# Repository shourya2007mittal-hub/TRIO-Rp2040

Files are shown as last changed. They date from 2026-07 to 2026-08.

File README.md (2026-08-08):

# TRIO-Rp2040


So I made on a Dev-board based on Rp-2040 with similar size constrain like Xiao-Rp2040 but with more available pins then Xiao. So I used the smallest size of resistors and capacitors . It has access to a total of 21 GPI0 and 4 Analog . 6 Pins act as dual purpose. It holds an USB-C Type interference for communication and 3.3V Voltage regulator and Crystal oscillator , Flash Memory , boot Switch  and more . 

## Why This

I made this as an alternative for  Xiao-Rp2040. Every time we need a small rp2040 microcontroller we surely need to go with Xiao boards . I made this so that I could use it for my upcoming projects related to Micro pad  and other IOT related things.

## Features

- Based on RP-2040 Chip
- Has MCP1700x-330xxTT as Voltage Regulator 
- Has W25Q16JVUXIQTR as Flash Memory
- Has 3 set of 7 connector pins  
- Has 2 set of 2 connector pins for GND and 3.3V
- It is compatible to a breadboard 

## Cost Summary (BOM)

| Item | Quantity | Price (USD) | Source |
|---|---|---|---|
| PCB + PCBA + Shipping  | 1 | $81.91 | JLCPCB |

**Total Estimated Cost:** **$81.91**

### Schematic


### PCB Design



### 3D Design



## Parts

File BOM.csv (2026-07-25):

Item | Quantity | Price | Source
PCB + PCBA + Shipping | 1 | 81.91 | JLCPCB

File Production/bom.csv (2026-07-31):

Designator | Footprint | Quantity | Value | LCSC Part #
C1 | 0201 | 1 | 1uF
C13, C14 | 0201 | 2 | 10uF
C15, C16 | 0201 | 2 | 33pF
C17, C2, C3, C4 | 0201 | 4 | 0.1uF
J1 | USB_C_Receptacle_G-Switch_GT-USB-7010ASV | 1 | USB_C_Receptacle_USB2.0_16P
J2, J3 | Molex_SL_171971-0008_1x08_P2.54mm_Vertical | 2 | Conn_01x08_Pin
R1, R2 | 0201 | 2 | 33 R
R3, R4 | 0201 | 2 | 50K
R5, R6 | 0201 | 2 | 1K
R7 | 0201 | 1 | 10K
SW1 | SW_Push_SPST_NO_Alps_SKRK | 1 | SW_Push
U1 | QFN-56-1EP_7x7mm_P0.4mm_EP3.2x3.2mm | 1 | RP2040
U2 | SOT-23 | 1 | MCP1700x-330xxTT
U4 | Winbond_USON-8-1EP_3x2mm_P0.5mm_EP0.2x1.6mm | 1 | W25Q16JVUXIQ TR
Y1 | Crystal_SMD_1210-4Pin_1.2x1.0mm | 1 | 12 MHz

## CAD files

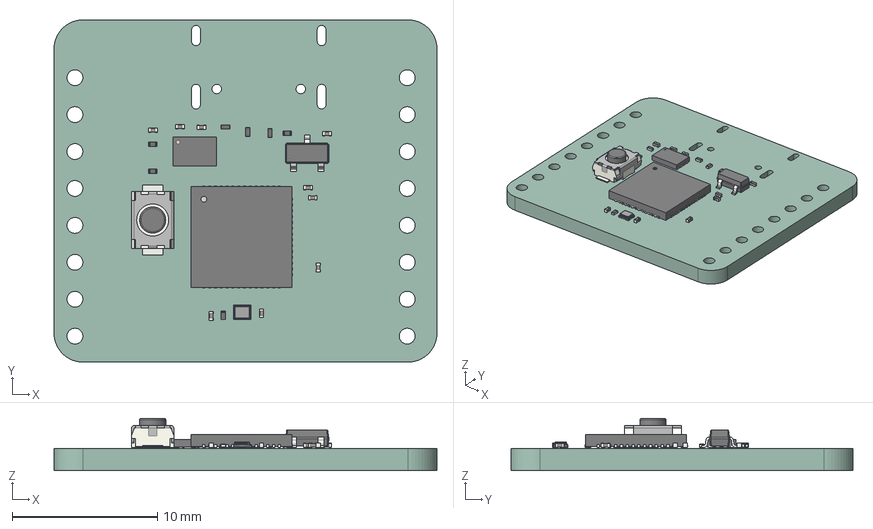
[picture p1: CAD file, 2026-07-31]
CAD/TRIO Rp2040.step
26.4 x 23.6 x 3.59 mm
R_0201_0603Metric x 7
C_0201_0603Metric x 9
Crystal_SMD_1210-4Pin_1.2x1.0mm
Winbond_USON-8-1EP_3x2mm_P0.5mm_EP0.2x1.6mm
SOT-23
QFN-56-1EP_7x7mm_P0.4mm_EP3.2x3.2mm
SW_Push_SPST_NO_Alps_SKRK
TRIO Rp2040_PCB

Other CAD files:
CAD/TRIO Rp2040.f3d

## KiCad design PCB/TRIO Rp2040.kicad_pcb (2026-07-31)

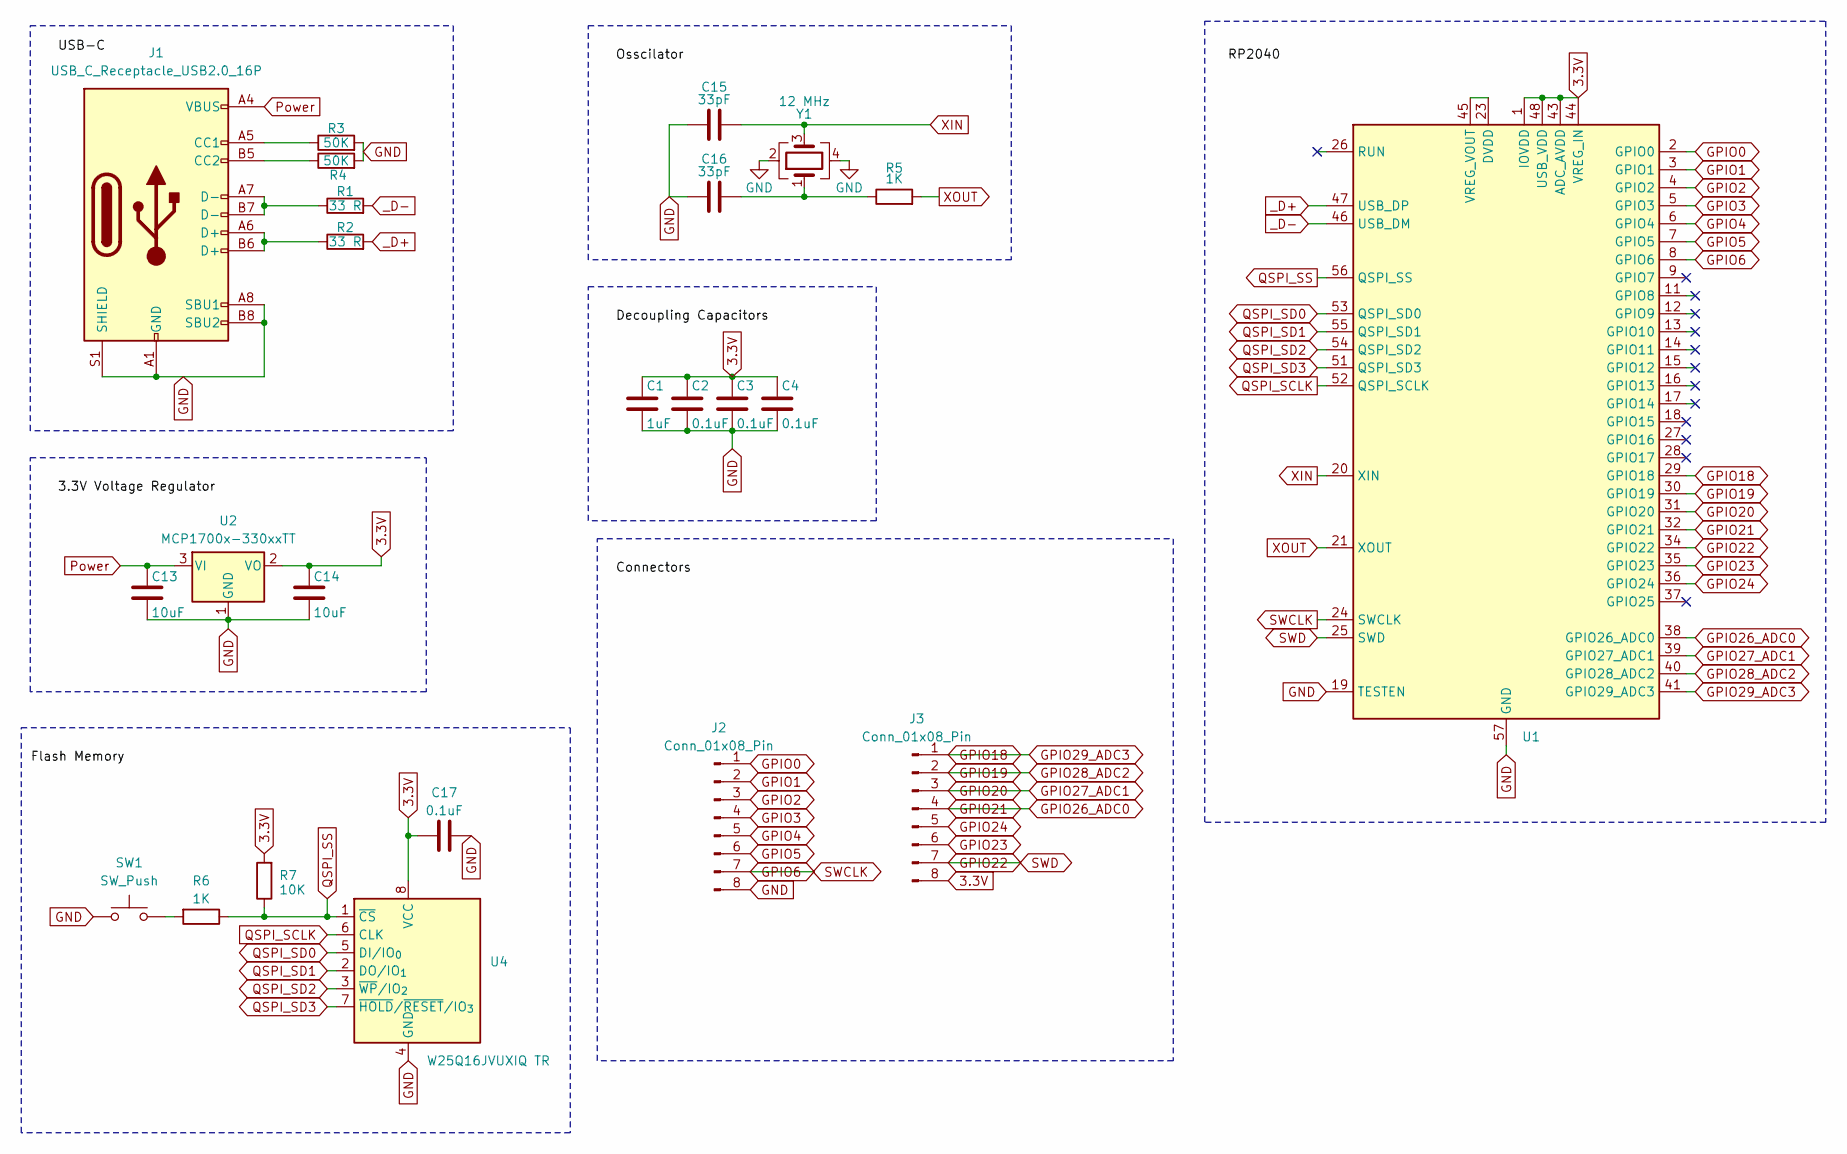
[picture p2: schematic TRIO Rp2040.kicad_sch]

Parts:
C1: 1uF; C_0201_0603Metric
C2, C3, C4, C17: 0.1uF; C_0201_0603Metric
C13, C14: 10uF; C_0201_0603Metric
C15, C16: 33pF; C_0201_0603Metric
J1: USB_C_Receptacle_USB2.0_16P; USB_C_Receptacle_G-Switch_GT-USB-7010ASV
J2, J3: Conn_01x08_Pin; Molex_SL_171971-0008_1x08_P2.54mm_Vertical
R1, R2: 33 R; R_0201_0603Metric
R3, R4: 50K; R_0201_0603Metric
R5, R6: 1K; R_0201_0603Metric
R7: 10K; R_0201_0603Metric
SW1: SW_Push; SW_Push_SPST_NO_Alps_SKRK
U1: RP2040; QFN-56-1EP_7x7mm_P0.4mm_EP3.2x3.2mm
U2: MCP1700x-330xxTT; SOT-23
U4: W25Q16JVUXIQ TR; Winbond_USON-8-1EP_3x2mm_P0.5mm_EP0.2x1.6mm
Y1: 12 MHz; Crystal_SMD_1210-4Pin_1.2x1.0mm

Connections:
3.3V: C1.1, C2.1, C3.1, C4.1, C14.1, C17.1, J3.8, R7.2, U1.1 (IOVDD), U1.10 (IOVDD), U1.22 (IOVDD), U1.33 (IOVDD), U1.42 (IOVDD), U1.43 (ADC_AVDD), U1.44 (VREG_IN), U1.48 (USB_VDD), U1.49 (IOVDD), U2.2 (VO), U4.8 (VCC)
GND: C1.2, C2.2, C3.2, C4.2, C13.2, C14.2, C15.1, C16.1, C17.2, J1.A1 (GND), J1.A8 (SBU1), J1.A12 (GND), J1.B1 (GND), J1.B8 (SBU2), J1.B12 (GND), J1.S1 (SHIELD), J2.8, R3.2, R4.2, SW1.1, U1.19 (TESTEN), U1.57 (GND), U2.1 (GND), U4.4 (GND), Y1.2, Y1.4
GPIO0: J2.1, U1.2 (GPIO0)
GPIO1: J2.2, U1.3 (GPIO1)
GPIO2: J2.3, U1.4 (GPIO2)
GPIO3: J2.4, U1.5 (GPIO3)
GPIO4: J2.5, U1.6 (GPIO4)
GPIO5: J2.6, U1.7 (GPIO5)
GPIO6: J2.7, U1.8 (GPIO6), U1.24 (SWCLK)
GPIO18: J3.1, U1.29 (GPIO18), U1.41 (GPIO29_ADC3)
GPIO19: J3.2, U1.30 (GPIO19), U1.40 (GPIO28_ADC2)
GPIO20: J3.3, U1.31 (GPIO20), U1.39 (GPIO27_ADC1)
GPIO21: J3.4, U1.32 (GPIO21), U1.38 (GPIO26_ADC0)
GPIO22: J3.7, U1.25 (SWD), U1.34 (GPIO22)
GPIO23: J3.6, U1.35 (GPIO23)
GPIO24: J3.5, U1.36 (GPIO24)
unnamed: C16.2, R5.1, Y1.1
unnamed: J1.A5 (CC1), R3.1
unnamed: J1.B5 (CC2), R4.1
unnamed: J1.A6 (D+), J1.B6 (D+), R2.1
unnamed: J1.A7 (D-), J1.B7 (D-), R1.1
unnamed: R6.2, SW1.2
unnamed: U1.23 (DVDD), U1.45 (VREG_VOUT), U1.50 (DVDD)
Power: C13.1, J1.A4 (VBUS), J1.A9 (VBUS), J1.B4 (VBUS), J1.B9 (VBUS), U2.3 (VI)
QSPI_SCLK: U1.52 (QSPI_SCLK), U4.6 (CLK)
QSPI_SD0: U1.53 (QSPI_SD0), U4.5 (DI/IO_{0})
QSPI_SD1: U1.55 (QSPI_SD1), U4.2 (DO/IO_{1})
QSPI_SD2: U1.54 (QSPI_SD2), U4.3 (~WP/IO_{2})
QSPI_SD3: U1.51 (QSPI_SD3), U4.7 (~HOLD/~RESET/IO_{3})
QSPI_SS: R6.1, R7.1, U1.56 (QSPI_SS), U4.1 (~CS)
XIN: C15.2, U1.20 (XIN), Y1.3
XOUT: R5.2, U1.21 (XOUT)
_D+: R2.2, U1.47 (USB_DP)
_D-: R1.2, U1.46 (USB_DM)

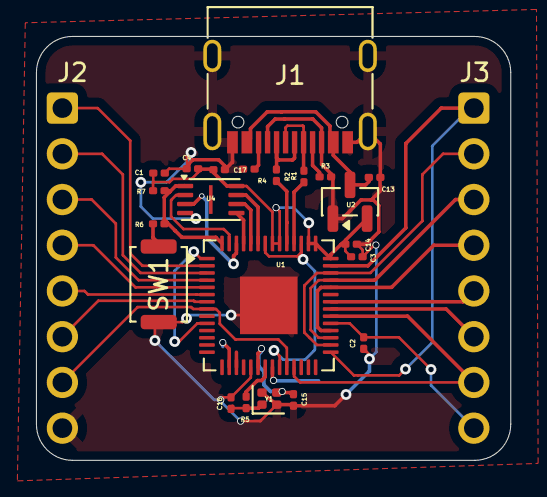
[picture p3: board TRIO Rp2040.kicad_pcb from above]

Board: 2 copper layers, 26.4 x 23.5 mm, 24 parts (0 on the bottom side), 34 nets.
